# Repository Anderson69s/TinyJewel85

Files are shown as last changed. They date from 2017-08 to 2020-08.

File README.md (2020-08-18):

# TinyJewel85

A little board that allow you to customise a necklace or a jewel.

## Getting Started

These instructions will help you to use and change the behavior of the LED on your TinyJewel85.

### Pre-requisites

```
Arduino IDE > 1.5.8
```
```
Adafruit NeoPixel Librairy
```
```
Add ATTINY85 board to Arduino IDE
```

### Installing

A step by step tutorial is on my site : https://atelierdumaker.com/portfolio/tinyjewel85/

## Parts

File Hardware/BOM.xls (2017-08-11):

BOM TinyJewel85
Components | Description | Ref PCB | Number | Suppliers | Ref Suppliers
MICRO
ATTINY85-20SU | MCU 8 bits, ATtiny, 20 MHz, 8 KB, 512 Byte, 8 Pins, SOIC | UC1 | 1 | RS-Components | 133-1674
POWER
Battery Connector | Wire-To-Board Connector, 2 mm, 2 Contacts, Header, PH Series, Surface Mount, 1 Rows | P1 | 1 | Farnell | 38K8067
Battery Holder | 3003 - Battery Contact, Coin Cell - 20mm, Through Hole, Phosphor Bronze, Nickel Plated Contacts | BT | 1 | Farnell | 66F5625
Battery | Lithium Ion Polymer Battery - 3.7v 150mAh |  | 1 | Adafruit | 1317
LiPo Charger | Adafruit Micro Lipo - USB Li-on/LiPoly charger – v1 |  | 1 | Adafruit | 1304
LEDS
LED | SK6812 Natural | D1, D2, D3 | 3 | Adafruit | 2758
LED | SK6812 Cool | D1, D2, D3 | 3 | Adafruit | 2759
LED | SK6812 Warm | D1, D2, D3 | 3 | Adafruit | 2757
Capacitors | Multilayer Ceramic Capacitor, MC Series, 0.1 F, 10%, X7R, 16 V, 0402 [1005 Metric] | C1, C2,C3,C4 | 4 | Farnell | 33R0276
BUTONS
Push Buton | Tactile Switch, Non Illuminated, 12 V, 50 mA, 320 gf, Solder, DTS Series | Animations | 1 | Farnell | 96K8956
Switch ON//OFF | Slide Switch, JS Series, DPDT, Vertical, SMD, 100 mA | ON // OFF | 1 | Farnell | JS202011SCQN

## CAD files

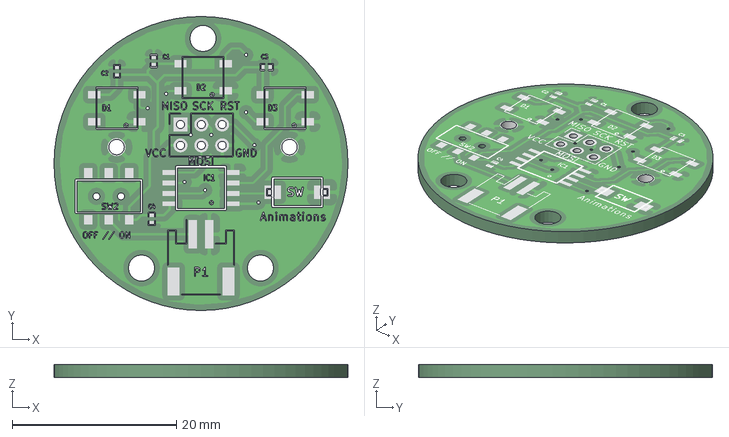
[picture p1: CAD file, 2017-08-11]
Hardware/3DShapes/TinyJewel85.3mf
35.8 x 35.8 x 1.70 mm

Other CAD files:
Hardware/3DShapes/TinyJewel85.stl

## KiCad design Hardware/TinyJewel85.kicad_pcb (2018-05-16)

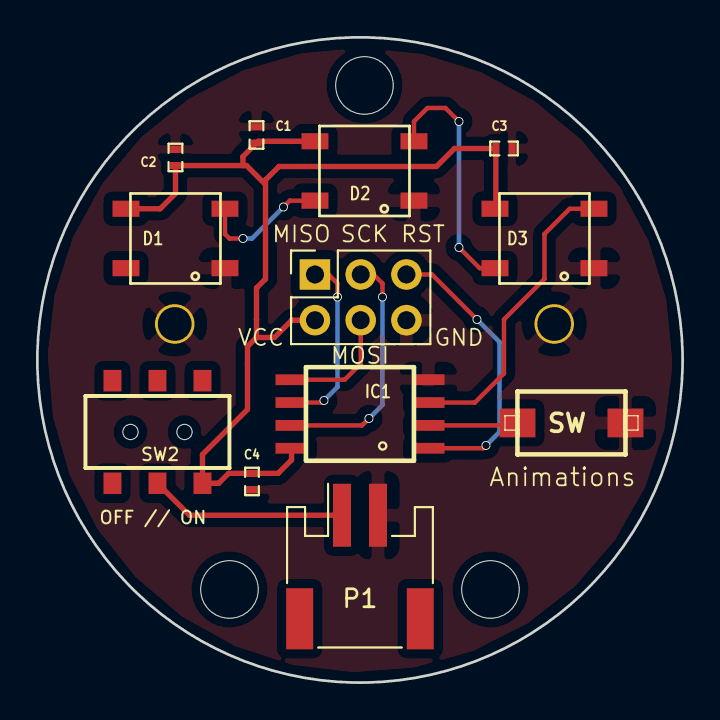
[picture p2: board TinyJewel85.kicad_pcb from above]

Board: 2 copper layers, 35.8 x 35.8 mm, 10 parts (0 on the bottom side), 6 nets.

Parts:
C1, C2, C3, C4: SM0402
D1, D2, D3: WS2812B
IC1: SOIC8-W
SW: SWITCH_CMS
SW2: OFF // ON; Switch_DPDT

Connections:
+3V3: C1.1, C2.1, C3.1, C4.1, D1.1, D2.1, D3.1, IC1.8, SW2.1
GND: C1.2, C2.2, C3.2, C4.2, D1.3, D2.3, D3.3, IC1.4, SW.2
unnamed: D1.4, D2.2
unnamed: D2.4, D3.2
PB3: IC1.2, SW.1
PB4: D3.4, IC1.3

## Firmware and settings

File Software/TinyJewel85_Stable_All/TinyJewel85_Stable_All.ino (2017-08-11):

/*
Many thank's to :
- Davis A. Mellis : http://highlowtech.org/?p=1695
- Jeff Saltzman : http://forum.arduino.cc/index.php?topic=14479.0
- Arduino Fundation : https://arduino.cc
- Adafruit : https://adafruit.com
*/

#include <Adafruit_NeoPixel.h>
#ifdef __AVR__
#include <avr/power.h>
#endif

// Pattern types supported:
enum  pattern {
  NONE, RAINBOW_CYCLE, THEATER_CHASE, COLOR_WIPE, SCANNER, FADE
};
// Patern directions supported:
enum  direction {
  FORWARD, REVERSE
};
float potard;// declare float to store potientiometer value
// NeoPattern Class - derived from the Adafruit_NeoPixel class
class NeoPatterns :
  public Adafruit_NeoPixel
{
  public:

    // Member Variables:
    pattern  ActivePattern;  // which pattern is running
    direction Direction;     // direction to run the pattern

    unsigned long Interval;   // milliseconds between updates
    unsigned long lastUpdate; // last update of position

    uint32_t Color1, Color2;  // What colors are in use
    uint16_t TotalSteps;  // total number of steps in the pattern
    uint16_t Index;  // current step within the pattern

    void (*OnComplete)();  // Callback on completion of pattern

    // Constructor - calls base-class constructor to initialize strip
    NeoPatterns(uint16_t pixels, uint8_t pin, uint8_t type, void (*callback)())
      :
      Adafruit_NeoPixel(pixels, pin, type)
    {
      OnComplete = callback;
    }

    // Update the pattern
    void Update()
    {
      if ((millis() - lastUpdate) > Interval) // time to update
      {
        lastUpdate = millis();
        switch (ActivePattern)
        {
          case RAINBOW_CYCLE:
            RainbowCycleUpdate();
            break;
          case THEATER_CHASE:
            TheaterChaseUpdate();
            break;
          case COLOR_WIPE:
            ColorWipeUpdate();
            break;
          case SCANNER:
            ScannerUpdate();
            break;
          case FADE:
            FadeUpdate();
            break;
          default:
            break;
        }
      }
    }

    // Increment the Index and reset at the end
    void Increment()
    {
      if (Direction == FORWARD)
      {
        Index++;
        if (Index >= TotalSteps)
        {
          Index = 0;
          if (OnComplete != NULL)
          {
            OnComplete(); // call the comlpetion callback
          }
        }
      }
      else // Direction == REVERSE
      {
        --Index;
        if (Index <= 0)
        {
          Index = TotalSteps - 1;
          if (OnComplete != NULL)
          {
            OnComplete(); // call the comlpetion callback
          }
        }
      }
    }

    // Reverse pattern direction
    void Reverse()
    {
      if (Direction == FORWARD)
      {
        Direction = REVERSE;
        Index = TotalSteps - 1;
      }
      else
      {
        Direction = FORWARD;
        Index = 0;
      }
    }

    // Initialize for a RainbowCycle
    void RainbowCycle(uint8_t interval, direction dir = FORWARD)
    {
      ActivePattern = RAINBOW_CYCLE;
      Interval = interval;
      TotalSteps = 255;
      Index = 0;
      Direction = dir;
    }

    // Update the Rainbow Cycle Pattern
    void RainbowCycleUpdate()
    {
      for (int i = 0; i < numPixels(); i++)
      {
        uint32_t wheelColor = Wheel(((i * 256 / numPixels()) + Index) & 255);
        setPixelColor(i, (Red(wheelColor) * potard), (Green(wheelColor) * potard), (Blue(wheelColor) * potard));
      }
      show();
      Increment();
    }

    // Initialize for a Theater Chase
    void TheaterChase(uint32_t color1, uint32_t color2, uint8_t interval, direction dir = FORWARD)
    {
      ActivePattern = THEATER_CHASE;
      Interval = interval;
      TotalSteps = numPixels();
      Color1 = color1;
      Color2 = color2;
      Index = 0;
      Direction = dir;
    }

    // Update the Theater Chase Pattern
    void TheaterChaseUpdate()
    {
      for (int i = 0; i < numPixels(); i++)
      {
        if ((i + Index) % 3 == 0)
        {
          setPixelColor(i, Color1);
        }
        else
        {
          setPixelColor(i, Color2);
        }
      }
      show();
      Increment();
    }

    // Initialize for a ColorWipe
    void ColorWipe(uint32_t color, uint8_t interval, direction dir = FORWARD)
    {
      ActivePattern = COLOR_WIPE;
      Interval = interval;
      TotalSteps = numPixels();
      Color1 = color;
      Index = 0;
      Direction = dir;
    }

    // Update the Color Wipe Pattern
    void ColorWipeUpdate()
    {
      setPixelColor(Index, Color1);
      show();
      Increment();
    }

    // Initialize for a SCANNNER
    void Scanner(uint32_t color1, uint8_t interval)
    {
      ActivePattern = SCANNER;
      Interval = interval;
      TotalSteps = (numPixels() - 1) * 2;
      Color1 = color1;
      Index = 0;
    }

    // Update the Scanner Pattern
    void ScannerUpdate()
    {
      for (int i = 0; i < numPixels(); i++)
      {
        if (i == Index)  // Scan Pixel to the right
        {
          setPixelColor(i, Color1);
        }
        else if (i == TotalSteps - Index) // Scan Pixel to the left
        {
          setPixelColor(i, Color1);
        }
        else // Fading tail
        {
          setPixelColor(i, DimColor(getPixelColor(i)));
        }
      }
      show();
      Increment();
    }

    // Initialize for a Fade
    void Fade(uint32_t color1, uint32_t color2, uint16_t steps, uint8_t interval, direction dir = FORWARD)
    {
      ActivePattern = FADE;
      Interval = interval;
      TotalSteps = steps;
      Color1 = color1;
      Color2 = color2;
      Index = 0;
      Direction = dir;
    }

    // Update the Fade Pattern
    void FadeUpdate()
    {
      // Calculate linear interpolation between Color1 and Color2
      // Optimise order of operations to minimize truncation error
      uint8_t red = ((Red(Color1) * (TotalSteps - Index)) + (Red(Color2) * Index)) / TotalSteps;
      uint8_t green = ((Green(Color1) * (TotalSteps - Index)) + (Green(Color2) * Index)) / TotalSteps;
      uint8_t blue = ((Blue(Color1) * (TotalSteps - Index)) + (Blue(Color2) * Index)) / TotalSteps;

      ColorSet(Color(red, green, blue));
      show();
      Increment();
    }

    // Calculate 50% dimmed version of a color (used by ScannerUpdate)
    uint32_t DimColor(uint32_t color)
    {
      // Shift R, G and B components one bit to the right
      uint32_t dimColor = Color(Red(color) >> 1, Green(color) >> 1, Blue(color) >> 1);
      return dimColor;
    }

    // Set all pixels to a color (synchronously)
    void ColorSet(uint32_t color)
    {
      for (int i = 0; i < numPixels(); i++)
      {
        setPixelColor(i, color);
      }
      show();
    }

    // Returns the Red component of a 32-bit color
    uint8_t Red(uint32_t color)
    {
      return (color >> 16) & 0xFF;
    }

    // Returns the Green component of a 32-bit color
    uint8_t Green(uint32_t color)
    {
      return (color >> 8) & 0xFF;
    }

    // Returns the Blue component of a 32-bit color
    uint8_t Blue(uint32_t color)
    {
      return color & 0xFF;
    }

    // Input a value 0 to 255 to get a color value.
    // The colours are a transition r - g - b - back to r.
    uint32_t Wheel(byte WheelPos)
    {
      WheelPos = 255 - WheelPos;
      if (WheelPos < 85)
      {
        return Color(255 - WheelPos * 3, 0, WheelPos * 3);
      }
      else if (WheelPos < 170)
      {
        WheelPos -= 85;
        return Color(0, WheelPos * 3, 255 - WheelPos * 3);
      }
      else
      {
        WheelPos -= 170;
        return Color(WheelPos * 3, 255 - WheelPos * 3, 0);
      }
    }
};
//------------------------------------------------------------
//Completion Routines - get called on completion of a pattern
//------------------------------------------------------------

// Ring1 Completion Callback
void Ring1Complete()
{

}

// Define some NeoPatterns for the two rings
//  as well as some completion routines
NeoPatterns Ring1(3, 4, NEO_GRBW + NEO_KHZ800, Ring1Complete);

int showType = 1;//initialize to the first animation

// Initialize everything and prepare to start
void setup()
{
#if defined (__AVR_ATtiny85__)
  if (F_CPU == 8000000) clock_prescale_set(clock_div_1);
#endif
  pinMode(3, INPUT);//pull_up the button
  digitalWrite(3, HIGH );//set D3 to HIGH
  float potard =  0.05;// value brightness ( between 0 - 1)
  // Initialize all the pixelStrips
  Ring1.begin();
  Ring1.ActivePattern = NONE;
  Ring1.ColorSet(Ring1.Color(0, 0, 0, 255 * potard));
}

// Main loop
void loop()
{
  Ring1.Update();  // Update the rings.
  int b = checkButton();
  if (b == 1) clickEvent();
  if (b == 2) doubleClickEvent();
  if (b == 3) holdEvent();
  if (b == 4) longHoldEvent();
}

void clickEvent() {// Change animation
  showType++;
  if (showType > 22)
    showType = 1;
  startShow(showType);
}
void doubleClickEvent() {//Change to Mininum Luminosity
  potard =  0.05;
  startShow(showType);
}
void holdEvent() {//Change to Medium Luminosity
  potard =  0.35;
  startShow(showType);
}
void longHoldEvent() {//Change to Maximum Luminosity
  potard =  1;
  startShow(showType);
}

void startShow(int i) {//Chose between the animation
  switch (i) {
    case 1:
      //WHITE
      Ring1.ActivePattern = NONE;
      Ring1.ColorSet(Ring1.Color(0, 0, 0, 255 * potard));
      //Ring1.ColorSet(Ring1.Color(0, 0, 0, 255 * potard));
      break;
    case 2:
      //RAINBOWCYCLE
      Ring1.ActivePattern = NONE;
      Ring1.RainbowCycle(30);
      break;
    case 3:
      //RED
      Ring1.ActivePattern = NONE;
      Ring1.ColorSet(Ring1.Color(255 * potard, 0, 0, 0));
      break;
    case 4:
      //GREEN
      Ring1.ActivePattern = NONE;
      Ring1.ColorSet(Ring1.Color(0, 255 * potard, 0, 0));
      break;
    case 5:
      //BLUE
      Ring1.ActivePattern = NONE;
      Ring1.ColorSet(Ring1.Color(0, 0, 255 * potard, 0));
      break;
    case 6:
      //YELLOW
      Ring1.ActivePattern = NONE;
      Ring1.ColorSet(Ring1.Color(255 * potard, 255 * potard, 0, 0));
      break;
    case 7:
      //PURPLE
      Ring1.ActivePattern = NONE;
      Ring1.ColorSet(Ring1.Color(255 * potard, 0, 255 * potard, 0));
      break;
    case 8:
      //CYAN
      Ring1.ActivePattern = NONE;
      Ring1.ColorSet(Ring1.Color(0, 255 * potard, 255 * potard, 0));
      break;
    case 9:
      //THEATER CHASE WHITE
      Ring1.ActivePattern = NONE;
      Ring1.TheaterChase(Ring1.Color(0, 0, 0, 255 * potard), Ring1.Color(0, 0, 0, 0), 250);
      break;
    case 10:
      //THEATER CHASE RED
      Ring1.ActivePattern = NONE;
      Ring1.TheaterChase(Ring1.Color(255 * potard, 0, 0, 0), Ring1.Color(0, 0, 0, 0), 250);
      break;
    case 11:
      //THEATER CHASE GREEN
      Ring1.ActivePattern = NONE;
      Ring1.TheaterChase(Ring1.Color(0, 255 * potard, 0, 0), Ring1.Color(0, 0, 0, 0), 250);
      break;
    case 12:
      //THEATER CHASE BLUE
      Ring1.ActivePattern = NONE;
      Ring1.TheaterChase(Ring1.Color(0, 0, 255 * potard, 0), Ring1.Color(0, 0, 0, 0), 250);
      break;
    case 13:
      //THEATER CHASE YELLOW
      Ring1.ActivePattern = NONE;
      Ring1.TheaterChase(Ring1.Color(255 * potard, 255 * potard, 0, 0), Ring1.Color(0, 0, 0, 0), 250);
      break;
    case 14:
      //THEATER CHASE PURPLE
      Ring1.ActivePattern = NONE;
      Ring1.TheaterChase(Ring1.Color(255 * potard, 0, 255 * potard, 0), Ring1.Color(0, 0, 0, 0), 250);
      break;
    case 15:
      //THEATER CHASE CYAN
      Ring1.ActivePattern = NONE;
      Ring1.TheaterChase(Ring1.Color(0, 255 * potard, 255 * potard, 0), Ring1.Color(0, 0, 0, 0), 250);
      break;
    case 16:
      //SCANNER WHITE
      Ring1.ActivePattern = NONE;
      Ring1.Scanner(Ring1.Color(0, 0, 0, 255 * potard), 500);
      break;
    case 17:
      //SCANNER RED
      Ring1.ActivePattern = NONE;
      Ring1.Scanner(Ring1.Color(255 * potard, 0, 0, 0), 500);
      break;
    case 18:
      //SCANNER GREEN
      Ring1.ActivePattern = NONE;
      Ring1.Scanner(Ring1.Color(0, 255 * potard, 0, 0), 500);
      break;
    case 19:
      //SCANNER BLUE
      Ring1.ActivePattern = NONE;
      Ring1.Scanner(Ring1.Color(0, 0, 255 * potard, 0), 500);
      break;
    case 20:
      //SCANNER YELLOW
      Ring1.ActivePattern = NONE;
      Ring1.Scanner(Ring1.Color(255 * potard, 255 * potard, 0, 0), 500);
      break;
    case 21:
      //SCANNER PURPLE
      Ring1.ActivePattern = NONE;
      Ring1.Scanner(Ring1.Color(255 * potard, 0, 255 * potard, 0), 500);
      break;
    case 22:
      //SCANNER CYAN
      Ring1.ActivePattern = NONE;
      Ring1.Scanner(Ring1.Color(0, 255 * potard, 255 * potard, 0), 500);
      break;
  }
}

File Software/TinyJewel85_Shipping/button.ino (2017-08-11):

//By Jeff Saltzman
//Oct. 13, 2009
//http://forum.arduino.cc/index.php?topic=14479.0
//  MULTI-CLICK:  One Button, Multiple Events

// Button timing variables
int debounce = 20;          // ms debounce period to prevent flickering when pressing or releasing the button
int DCgap = 250;            // max ms between clicks for a double click event
int holdTime = 1000;        // ms hold period: how long to wait for press+hold event
int longHoldTime = 3000;    // ms long hold period: how long to wait for press+hold event

// Button variables
boolean buttonVal = HIGH;   // value read from button
boolean buttonLast = HIGH;  // buffered value of the button's previous state
boolean DCwaiting = false;  // whether we're waiting for a double click (down)
boolean DConUp = false;     // whether to register a double click on next release, or whether to wait and click
boolean singleOK = true;    // whether it's OK to do a single click
long downTime = -1;         // time the button was pressed down
long upTime = -1;           // time the button was released
boolean ignoreUp = false;   // whether to ignore the button release because the click+hold was triggered
boolean waitForUp = false;        // when held, whether to wait for the up event
boolean holdEventPast = false;    // whether or not the hold event happened already
boolean longHoldEventPast = false;// whether or not the long hold event happened already

int checkButton() {    
   int event = 0;
   buttonVal = digitalRead(3);
   // Button pressed down
   if (buttonVal == LOW && buttonLast == HIGH && (millis() - upTime) > debounce)
   {
       downTime = millis();
       ignoreUp = false;
       waitForUp = false;
       singleOK = true;
       holdEventPast = false;
       longHoldEventPast = false;
       if ((millis()-upTime) < DCgap && DConUp == false && DCwaiting == true)  DConUp = true;
       else  DConUp = false;
       DCwaiting = false;
   }
   // Button released
   else if (buttonVal == HIGH && buttonLast == LOW && (millis() - downTime) > debounce)
   {        
       if (not ignoreUp)
       {
           upTime = millis();
           if (DConUp == false) DCwaiting = true;
           else
           {
               event = 2;
               DConUp = false;
               DCwaiting = false;
               singleOK = false;
           }
       }
   }
   // Test for normal click event: DCgap expired
   if ( buttonVal == HIGH && (millis()-upTime) >= DCgap && DCwaiting == true && DConUp == false && singleOK == true && event != 2)
   {
       event = 1;
       DCwaiting = false;
   }
   // Test for hold
   if (buttonVal == LOW && (millis() - downTime) >= holdTime) {
       // Trigger "normal" hold
       if (not holdEventPast)
       {
           event = 3;
           waitForUp = true;
           ignoreUp = true;
           DConUp = false;
           DCwaiting = false;
           //downTime = millis();
           holdEventPast = true;
       }
       // Trigger "long" hold
       if ((millis() - downTime) >= longHoldTime)
       {
           if (not longHoldEventPast)
           {
               event = 4;
               longHoldEventPast = true;
           }
       }
   }
   buttonLast = buttonVal;
   return event;
}

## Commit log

2017-08-11 Initial Commit
    First Realease
    [BOM.xls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]
2018-05-16 Update Kicad
    Jump from 4.0.6 to 4.0.7
    [TinyJewel85.kicad_pcb]
